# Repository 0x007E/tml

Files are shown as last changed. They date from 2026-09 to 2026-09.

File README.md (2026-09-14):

  

# `TML` - Temperature Logger

The `TML` is a board with an [LM386](#additional-information) that is used to scale up a temperature (0°-100°) from [KT200](#additional-information). The temperature gets A/D converted over an [ATtiny1606](#additional-information) and is stored in an eeprom [AT24CM0X](#additional-information) with current time and date that is provided by a [MCP7940](#additional-information) r(eal)-t(ime)-c(lock). The board itself provides a reverse polarity protection and can be supplied between `9-12V`. The voltage is line regulated to `5V`.

| Experience | Level |
|:---|:-----:|
| Soldering | ?% |

# Downloads

| Type | File | Description |
|:---:|:---:|:---|
| Schematic | [pdf](https://github.com/0x007E/tml/releases/latest/download/schematic.pdf) / [cadlab](https://cadlab.io/project/30575/main/files) | Schematic files |
| Board | [pdf](https://github.com/0x007E/tml/releases/latest/download/pcb.pdf) / [cadlab](https://cadlab.io/project/30575/main/files) | Board file |
| Drill | [pdf](https://github.com/0x007E/tml/releases/latest/download/drill.pdf) | Drill file |
| BoM | [xlsx](https://github.com/0x007E/tml/releases/latest/download/bom.xlsx) / [html](https://github.com/0x007E/tml/releases/latest/download/ibom.html) | Bill of Material as Excel/interactive HTML |
| PCB | [zip](https://github.com/0x007E/tml/releases/latest/download/kicad.zip) / [tar](https://github.com/0x007E/tml/releases/latest/download/kicad.tar.gz) | KiCAD/Gerber/BoM/Drill files |

# Hardware

The pcb is created with `KiCAD`. All files are built with `github actions` so that they are ready for a production environment.

## PCB

The circuit board is populated on both sides (Top, Bottom). The best way for soldering the `SMD` components is within a vapor phase soldering system and for the `THT` components with a standard soldering system.

### Top Layer

Top Layer

### Bottom Layer

Bottom Layer

# Additional Information

| Type  | Link | Description |
|:---|:---:|:---|
| LM358 | [pdf](https://www.ti.com/lit/ds/symlink/lm358b.pdf) | Industry-Standard Dual Operational Amplifiers |
| KT200 | [pdf](https://rocelec.widen.net/view/pdf/qxp2nqwwr1/INFNS04262-1.pdf?t.download=true&u=5oefqw) | Silicon Temperature Sensors |
| ATtiny1606 | [pdf](https://ww1.microchip.com/downloads/en/DeviceDoc/ATtiny804-06-07-1604-06-07-DataSheet-DS40002312A.pdf) | tinyAVR® 0-series |
| AT24CM01 | [pdf](https://ww1.microchip.com/downloads/en/DeviceDoc/AT24CM01-I2C-Compatible-Two-Wire-Serial-EEPROM-Data-Sheet-20006170A.pdf) | I²C-Compatible (Two-Wire) Serial EEPROM 1‑Mbit (131,072 x 8) |
| AT24CM02 | [pdf](https://ww1.microchip.com/downloads/en/DeviceDoc/I%C2%B2C-Compatible-(Two-Wire)-Serial-EEPROM-2-Mbit-(262,144x8)-20006197B.pdf) | I²C-Compatible (Two-Wire) Serial EEPROM 2‑Mbit (262,144 x 8) |
| MCP7940 | [pdf](https://ww1.microchip.com/downloads/en/DeviceDoc/MCP7940M-Low-Cost%20I2C-RTCC-with-SRAM-20002292C.pdf) | Low-Cost I2C Real-Time Clock/Calendar with SRAM |

---

R. GAECHTER

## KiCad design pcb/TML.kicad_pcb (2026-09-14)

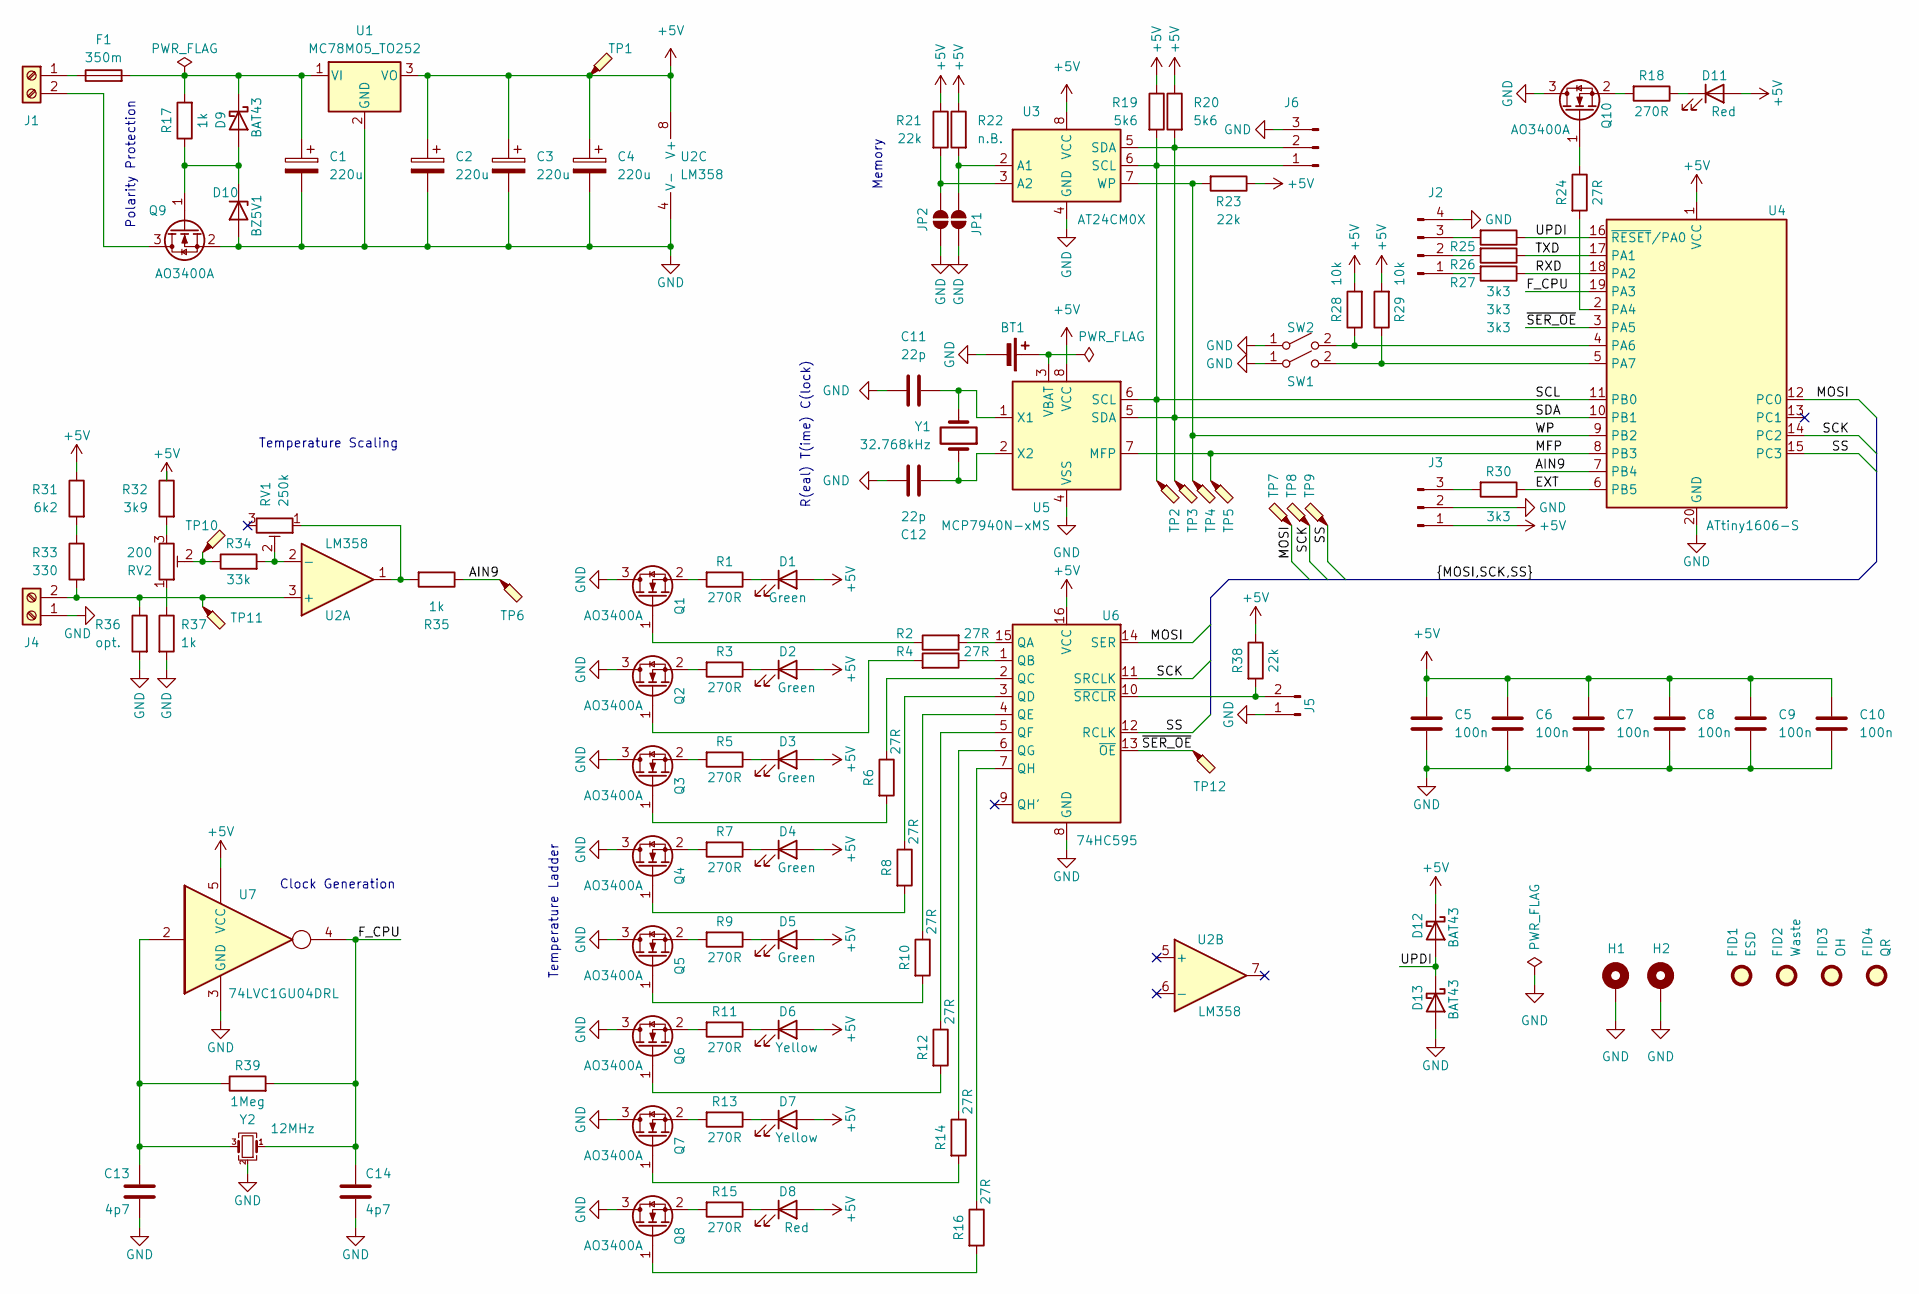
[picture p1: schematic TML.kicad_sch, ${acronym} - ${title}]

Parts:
BT1: Battery_Cell; BatteryHolder_LINX_BAT-HLD-012-SMT
C1, C2, C3, C4: 220u; CP_Radial_D8.0mm_P3.50mm
C5, C6, C7, C8, C9, C10: 100n; C_1206_3216Metric
C11, C12: 22p; C_1206_3216Metric
C13, C14: 4p7; C_1206_3216Metric
D1, D2, D3, D4, D5: Green; LED_D5.0mm
D6, D7: Yellow; LED_D5.0mm
D8: Red; LED_D5.0mm
D9, D12, D13: BAT43; D_MiniMELF
D10: BZ5V1; D_MiniMELF
D11: Red; LED_1206_3216Metric
F1: 350m; Fuse_1206_3216Metric
FID1: ESD; ESD-Logo_6.6x6mm_SilkScreen
FID2: Waste; WEEE-Logo_4.2x6mm_SilkScreen
FID3: OH; OSHW-Logo_5.7x6mm_SilkScreen
FID4: QR; QR_0x007e
H1, H2: MountingHole_Pad; MountingHole_3.2mm_M3_DIN965_Pad
J1, J4: Screw_Terminal_01x02; TerminalBlock_Phoenix_MKDS-1,5-2-5.08_1x02_P5.08mm_Horizont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
J2: Conn_01x04_Pin; PinHeader_1x04_P2.54mm_Vertical
J3, J6: Conn_01x03_Pin; PinHeader_1x03_P2.54mm_Vertical
J5: Conn_01x02_Pin; PinHeader_1x02_P2.54mm_Vertical
JP1, JP2: SolderJumper_2_Open; SolderJumper-2_P1.3mm_Open_RoundedPad1.0x1.5mm
Q1, Q2, Q3, Q4, Q5, Q6, Q7, Q8, Q9, Q10: AO3400A; SOT-23-3
R1, R3, R5, R7, R9, R11, R13, R15, R18: 270R; R_1206_3216Metric
R2, R4, R6, R8, R10, R12, R14, R16, R24: 27R; R_1206_3216Metric
R17, R35, R37: 1k; R_1206_3216Metric
R19, R20: 5k6; R_1206_3216Metric
R21, R23, R38: 22k; R_1206_3216Metric
R22: n.B.; R_1206_3216Metric
R25, R26, R27, R30: 3k3; R_1206_3216Metric
R28, R29: 10k; R_1206_3216Metric
R31: 6k2; R_1206_3216Metric
R32: 3k9; R_1206_3216Metric
R33: 330; R_1206_3216Metric
R34: 33k; R_1206_3216Metric
R36: opt.; R_1206_3216Metric
R39: 1Meg; R_1206_3216Metric
RV1: 250k; Potentiometer_Bourns_3296W_Vertical
RV2: 200; Potentiometer_Bourns_3296W_Vertical
SW1, SW2: SW_SPST; SW_PUSH_6mm
TP1, TP2, TP3, TP4, TP5, TP6, TP7, TP8, TP9, TP10, TP11, TP12: TestPoint_Probe; TestPoint_Pad_D1.5mm
U1: MC78M05_TO252; TO-252-2
U2: LM358; SOIC-8_3.9x4.9mm_P1.27mm
U3: AT24CM0X; SOIC-8_3.9x4.9mm_P1.27mm
U4: ATtiny1606-S; SOIC-20W_7.5x12.8mm_P1.27mm
U5: MCP7940N-xMS; SOIC-8_3.9x4.9mm_P1.27mm
U6: 74HC595; SOIC-16W_5.3x10.2mm_P1.27mm
U7: 74LVC1GU04DRL; SOT-553; DigiKey 296-18657-1-ND
Y1: 32.768kHz; Crystal_SMD_3215-2Pin_3.2x1.5mm
Y2: 12MHz; Crystal_SMD_Abracon_ABM8AIG-4Pin_3.2x2.5mm

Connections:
+5V: C2.1, C3.1, C4.1, C5.1, C6.1, C7.1, C8.1, C9.1, C10.1, D1.2 (A), D2.2 (A), D3.2 (A), D4.2 (A), D5.2 (A), D6.2 (A), D7.2 (A), D8.2 (A), D11.2 (A), D12.1 (K), J3.1, R19.1, R20.1, R21.1, R22.1, R23.1, R28.2, R29.2, R31.1, R32.1, R38.1, TP1.1, U1.3 (VO), U2.8 (V+), U3.8 (VCC), U4.1 (VCC), U5.8 (VCC), U6.16 (VCC), U7.5 (VCC)
/AIN9: R35.1, TP6.1, U4.7 (PB4)
/EXT: R30.1, U4.6 (PB5)
/F_CPU: C14.1, R39.2, U4.19 (PA3), U7.4, Y2.1
/MFP: TP5.1, U4.8 (PB3), U5.7 (MFP)
/MOSI: TP7.1, U4.12 (PC0), U6.14 (SER)
/RXD: R27.1, U4.18 (PA2)
/SCK: TP8.1, U4.14 (PC2), U6.11 (SRCLK)
/SCL: J6.1, R19.2, TP2.1, U3.6 (SCL), U4.11 (PB0), U5.6 (SCL)
/SDA: J6.2, R20.2, TP3.1, U3.5 (SDA), U4.10 (PB1), U5.5 (SDA)
/SS: TP9.1, U4.15 (PC3), U6.12 (RCLK)
/TXD: R26.1, U4.17 (PA1)
/UPDI: D12.2 (A), D13.1 (K), R25.1, U4.16 (~RESET/PA0)
/WP: R23.2, TP4.1, U3.7 (WP), U4.9 (PB2)
/~SER_OE: TP12.1, U4.3 (PA5), U6.13 (~OE)
GND: BT1.2 (-), C1.2, C2.2, C3.2, C4.2, C5.2, C6.2, C7.2, C8.2, C9.2, C10.2, C11.2, C12.2, C13.2, C14.2, D10.2 (A), D13.2 (A), H1.1, H2.1, J2.4, J3.2, J4.1, J5.1, J6.3, JP1.1 (A), JP2.1 (A), Q1.3 (D), Q2.3 (D), Q3.3 (D), Q4.3 (D), Q5.3 (D), Q6.3 (D), Q7.3 (D), Q8.3 (D), Q9.2 (S), Q10.3 (D), R36.2, R37.2, SW1.1 (A), SW2.1 (A), U1.2 (GND), U2.4 (V-), U3.4 (GND), U4.20 (GND), U5.4 (VSS), U6.8 (GND), U7.3 (GND), Y2.2 (G), Y2.4 (G)
unnamed: BT1.1 (+), U5.3 (VBAT)
unnamed: C13.1, R39.1, U7.2, Y2.3
unnamed: D1.1 (K), R1.1
unnamed: D2.1 (K), R3.1
unnamed: D3.1 (K), R5.1
unnamed: D4.1 (K), R7.1
unnamed: D5.1 (K), R9.1
unnamed: D6.1 (K), R11.1
unnamed: D7.1 (K), R13.1
unnamed: D8.1 (K), R15.1
unnamed: C1.1, D9.1 (K), F1.2, R17.2, U1.1 (VI)
unnamed: D9.2 (A), D10.1 (K), Q9.1 (G), R17.1
unnamed: D11.1 (K), R18.1
unnamed: F1.1, J1.1
unnamed: J1.2, Q9.3 (D)
unnamed: J2.1, R27.2
unnamed: J2.2, R26.2
unnamed: J2.3, R25.2
unnamed: J3.3, R30.2
unnamed: J4.2, R33.2, R36.1, TP11.1, U2.3 (+)
unnamed: J5.2, R38.2, U6.10 (~SRCLR)
unnamed: JP1.2 (B), R22.2, U3.2 (A1)
unnamed: JP2.2 (B), R21.2, U3.3 (A2)
unnamed: Q1.1 (G), R2.1
unnamed: Q1.2 (S), R1.2
unnamed: Q2.1 (G), R4.2
unnamed: Q2.2 (S), R3.2
unnamed: Q3.1 (G), R6.2
unnamed: Q3.2 (S), R5.2
unnamed: Q4.1 (G), R8.2
unnamed: Q4.2 (S), R7.2
unnamed: Q5.1 (G), R10.2
unnamed: Q5.2 (S), R9.2
unnamed: Q6.1 (G), R12.2
unnamed: Q6.2 (S), R11.2
unnamed: Q7.1 (G), R14.2
unnamed: Q7.2 (S), R13.2
unnamed: Q8.1 (G), R16.2
unnamed: Q8.2 (S), R15.2
unnamed: Q10.1 (G), R24.1
unnamed: Q10.2 (S), R18.2
unnamed: R31.2, R33.1
unnamed: R32.2, RV2.3
unnamed: R34.1, RV2.2, TP10.1
unnamed: R35.2, RV1.1, U2.1
unnamed: R37.1, RV2.1
unnamed: R29.1, SW1.2 (B), U4.5 (PA7)
unnamed: R28.1, SW2.2 (B), U4.4 (PA6)
unnamed: R34.2, RV1.2, U2.2 (-)
unnamed: R24.2, U4.2 (PA4)
unnamed: C11.1, U5.1 (X1), Y1.2
unnamed: C12.1, U5.2 (X2), Y1.1
unnamed: R2.2, U6.15 (QA)
unnamed: R4.1, U6.1 (QB)
unnamed: R6.1, U6.2 (QC)
unnamed: R8.1, U6.3 (QD)
unnamed: R10.1, U6.4 (QE)
unnamed: R12.1, U6.5 (QF)
unnamed: R14.1, U6.6 (QG)
unnamed: R16.1, U6.7 (QH)

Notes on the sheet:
Temperature Ladder
Memory
Polarity Protection
Temperature Scaling
R(eal) T(ime) C(lock)
Clock Generation

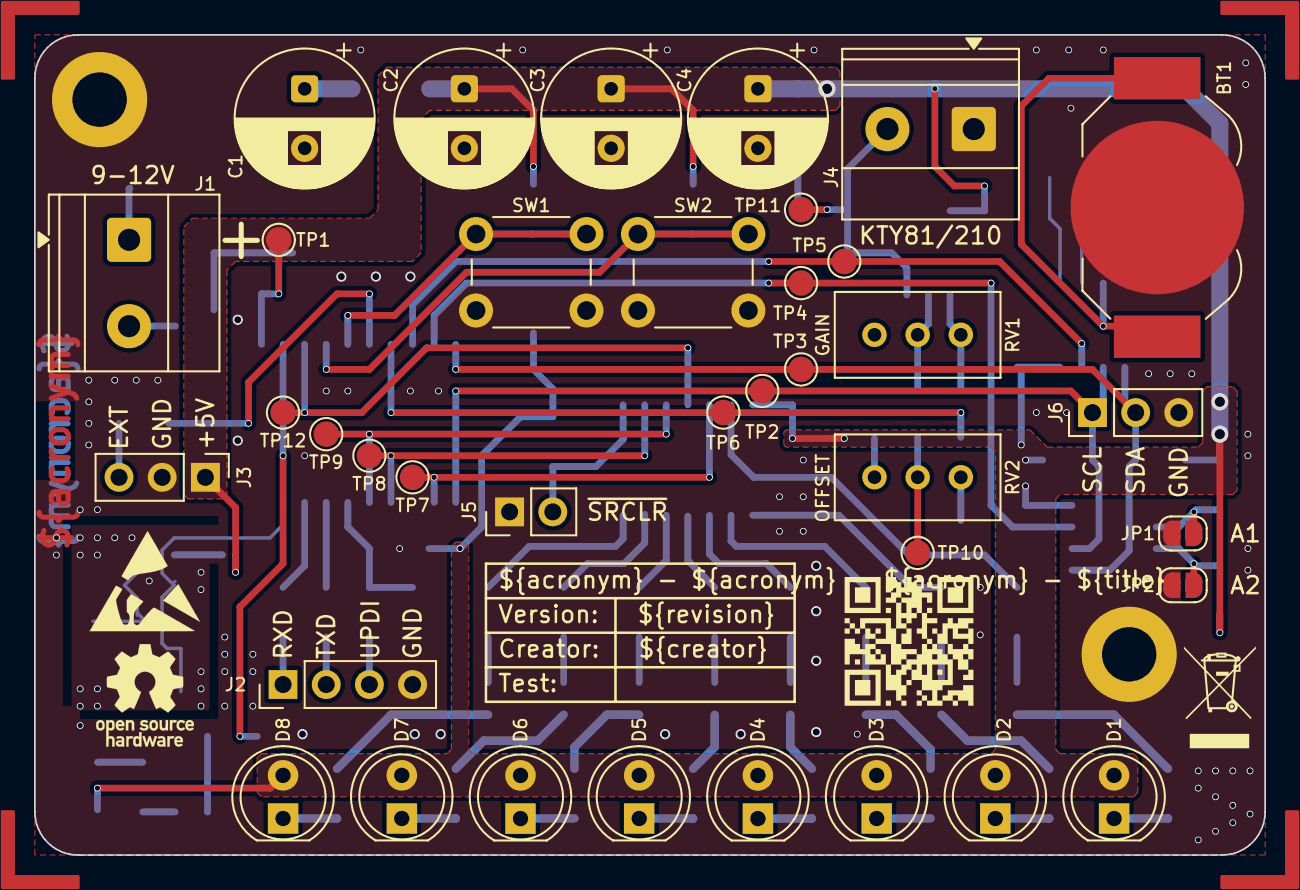
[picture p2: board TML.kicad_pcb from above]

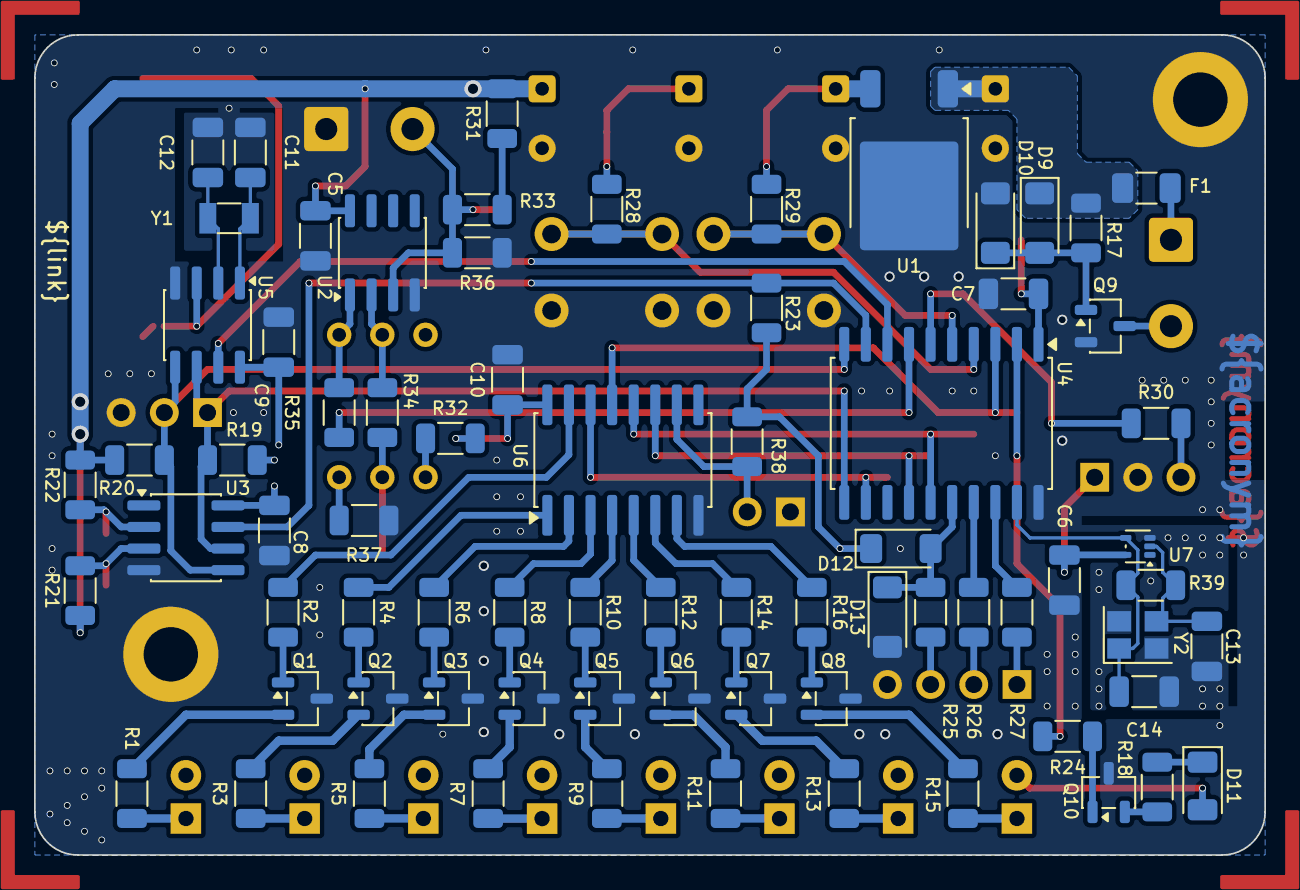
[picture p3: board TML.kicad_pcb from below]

Board: 2 copper layers, 72.4 x 48.3 mm, 117 parts (74 on the bottom side), 76 nets.

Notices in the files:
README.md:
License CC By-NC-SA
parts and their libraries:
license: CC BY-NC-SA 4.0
